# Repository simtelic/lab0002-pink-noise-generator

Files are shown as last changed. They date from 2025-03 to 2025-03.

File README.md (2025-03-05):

# Pink Noise Generator

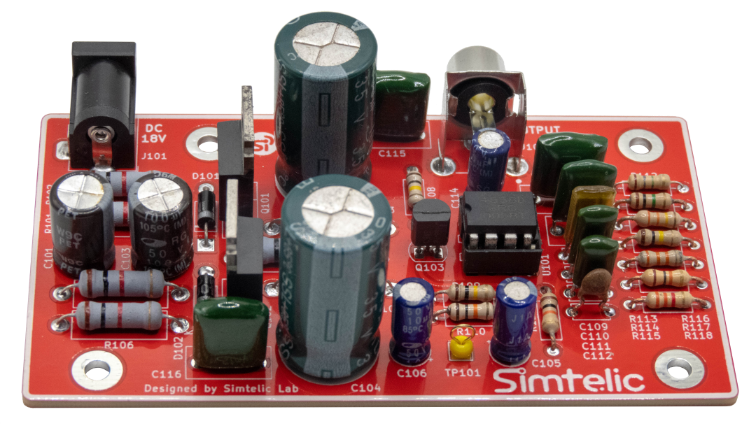
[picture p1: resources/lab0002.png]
LB0002 prototype build


This kit offers a simple yet effective DIY pink noise generator. It features a compact and user-friendly design that utilizes only three transistors and one operational amplifier, making it a cost-effective and educational option for exploring the unique characteristics of pink noise. All components are through-hole, ensuring that assembly is straightforward and suitable for hobbyists of varying skill levels.

The pink-noise generator operates with a DC power supply ranging from 12V to 18V and includes a single audio output that can be directly connected to a power amplifier or preamplifier for further amplification and playback.

This is an open hardware project, and all design files are available in this repository. You can also [order an unassembled DIY kit from Simtelic](https://simtelic.com/product/pink-noise-generator/), which includes the PCB and all the necessary components for assembly and testing.

[PCBWay](https://www.pcbway.com) sponsors this project, and you can [directly order the PCB](https://www.pcbway.com/project/shareproject/Analog_pink_noise_generator_595b019c.html) from them as well.

The [datasheet](https://simtelic.com/datasheet.php?id=lb0002) and [user manual](https://simtelic.com/datasheet.php?id=lb0002) for this project are available at [simtelic.com](https://simtelic.com).

## Bill of Materials

| Designator | Value | Quantity | Notes |
|---|---|---|---|
| C101,C103 | [100μF/25V](https://s.click.aliexpress.com/e/_omJ0Eoy) | 2 | |
| C102,C104 | [1000μF/25V](https://s.click.aliexpress.com/e/_olrI524) | 2 | |
| C105,C106,C114 | [10μF/25V](https://s.click.aliexpress.com/e/_ompkcr2) | 3 | |
| C107,C115,C116 | [0.1μF/50V](https://s.click.aliexpress.com/e/_okANxdw) | 3 | |
| C108 | [0.033μF/50V](https://s.click.aliexpress.com/e/_onlJl4o) | 1 | |
| C109 | [0.01μF/50V](https://s.click.aliexpress.com/e/_okQIYzA) | 1 | |
| C110 | [0.0033μF/50V](https://s.click.aliexpress.com/e/_oDFPQX2) | 1 | |
| C111 | [0.001μF/50V](https://s.click.aliexpress.com/e/_oDFPQX2) | 1 | |
| C112 | [330PF/50V](https://s.click.aliexpress.com/e/_oBugdCo) | 1 | |
| C113 | [100PF/50V](https://s.click.aliexpress.com/e/_oBugdCo) | 1 | |
| R101,R102,R104,R105,R106 | [1KΩ(5% 1W)](https://s.click.aliexpress.com/e/_oFf5dpE) | 5 | |
| R103,R107 | [2.2Ω(5% 1W)](https://s.click.aliexpress.com/e/_oFf5dpE) | 2 | |
| R108,R109,R115 | [100KΩ](https://s.click.aliexpress.com/e/_onyWV8u) | 3 | |
| R110,R111,R117 | [10KΩ](https://s.click.aliexpress.com/e/_onyWV8u) | 3 | |
| R112 | [1.8MΩ](https://s.click.aliexpress.com/e/_onyWV8u) | 1 | |
| R113 | [1MΩ](https://s.click.aliexpress.com/e/_onyWV8u) | 1 | |
| R114 | [330KΩ](https://s.click.aliexpress.com/e/_onyWV8u) | 1 | |
| R116 | [33KΩ](https://s.click.aliexpress.com/e/_onyWV8u) | 1 | |
| R118 | [3.3KΩ](https://s.click.aliexpress.com/e/_onyWV8u) | 1 | |
| D101,D102 | [1N4007](https://s.click.aliexpress.com/e/_oC87JiG) | 2 | https://www.vishay.com/docs/88503/1n4001.pdf |
| Q101 | [TIP31](https://s.click.aliexpress.com/e/_oDikbdi) | 1 | https://www.onsemi.com/download/data-sheet/pdf/tip31a-d.pdf |
| Q102 | [TIP32](https://s.click.aliexpress.com/e/_oDikbdi) | 1 | https://www.onsemi.com/download/data-sheet/pdf/tip32c-d.pdf |
| Q103 | [2SC945](https://s.click.aliexpress.com/e/_oCgKZjW) | 1 | https://datasheet.octopart.com/2SC945-Inchange-Semiconductor-datasheet-15979352.pdf |
| U101 | [NJM4558](https://s.click.aliexpress.com/e/_onCjzLQ) | 1 | https://www.nisshinbo-microdevices.co.jp/en/pdf/datasheet/NJM4558_E.pdf |
| J101 | [5.5mm DC Jack Socket](https://s.click.aliexpress.com/e/_o2awuTE) | 1 | |
| J102 | [RCA Jack Socket](https://s.click.aliexpress.com/e/_oEL5MTS) | 1 | |
| TP101 | [Test pin (optional)](https://s.click.aliexpress.com/e/_olBI9cC)  | 1 | |

*All resistors are 5% 1/4W unless otherwise noted*

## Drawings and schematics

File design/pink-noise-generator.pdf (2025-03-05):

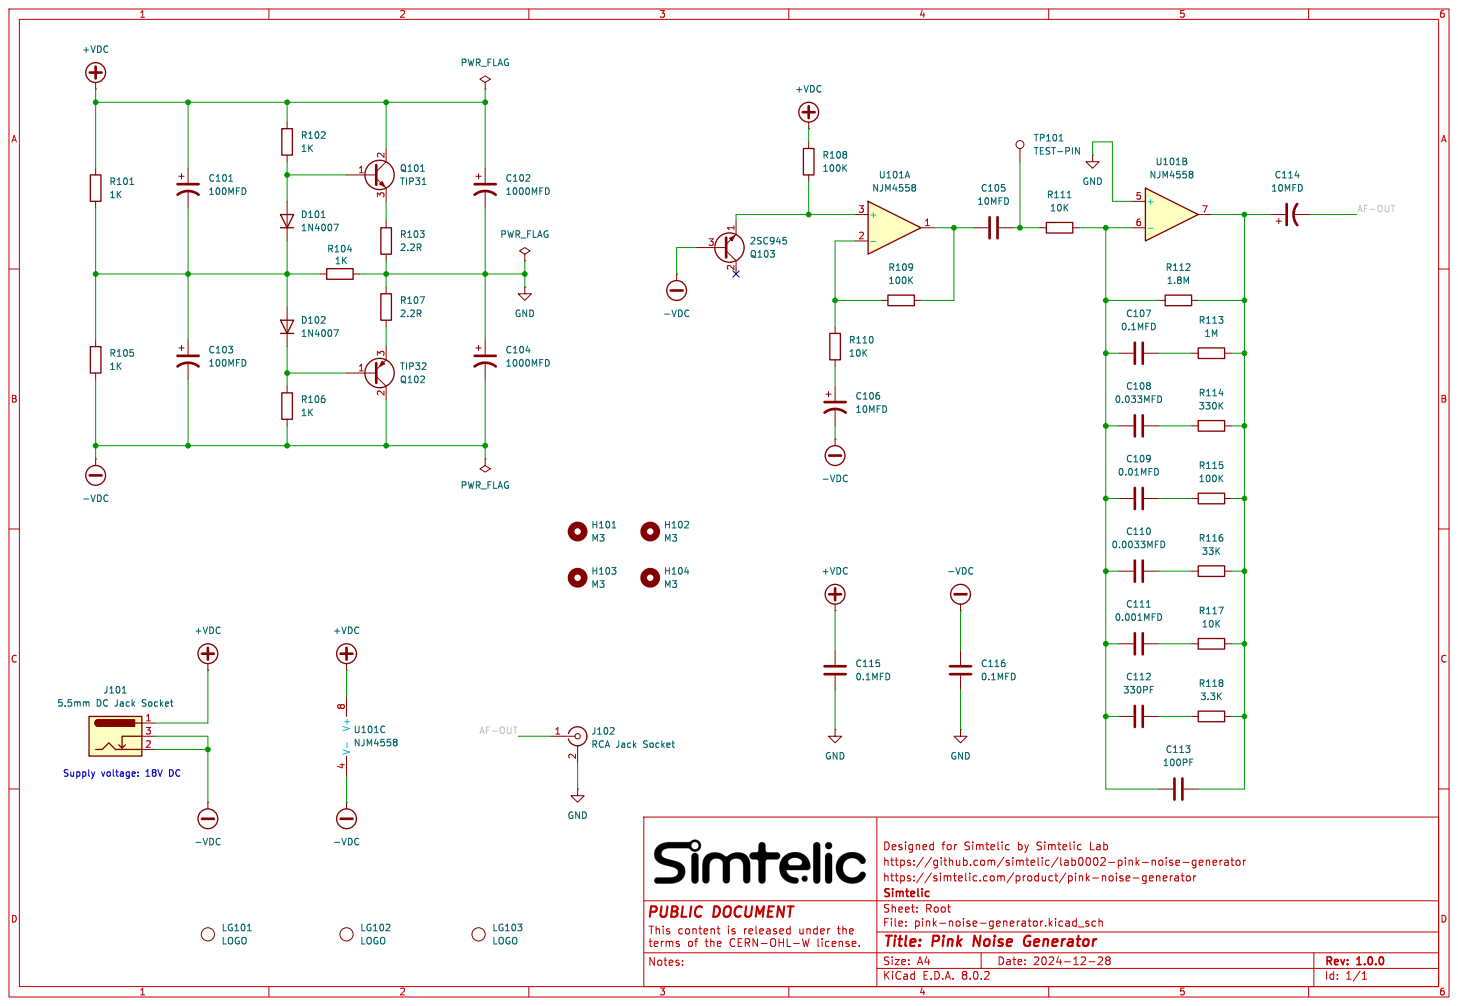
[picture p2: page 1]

J102 RCA Jack Socket GND

https://github.com/simtelic/lab0002-pink-noise-generator
https://simtelic.com/product/pink-noise-generator
Id: 1/1 Title: Pink Noise Generator File: pink-noise-generator.kicad_sch Sheet: Root Simtelic

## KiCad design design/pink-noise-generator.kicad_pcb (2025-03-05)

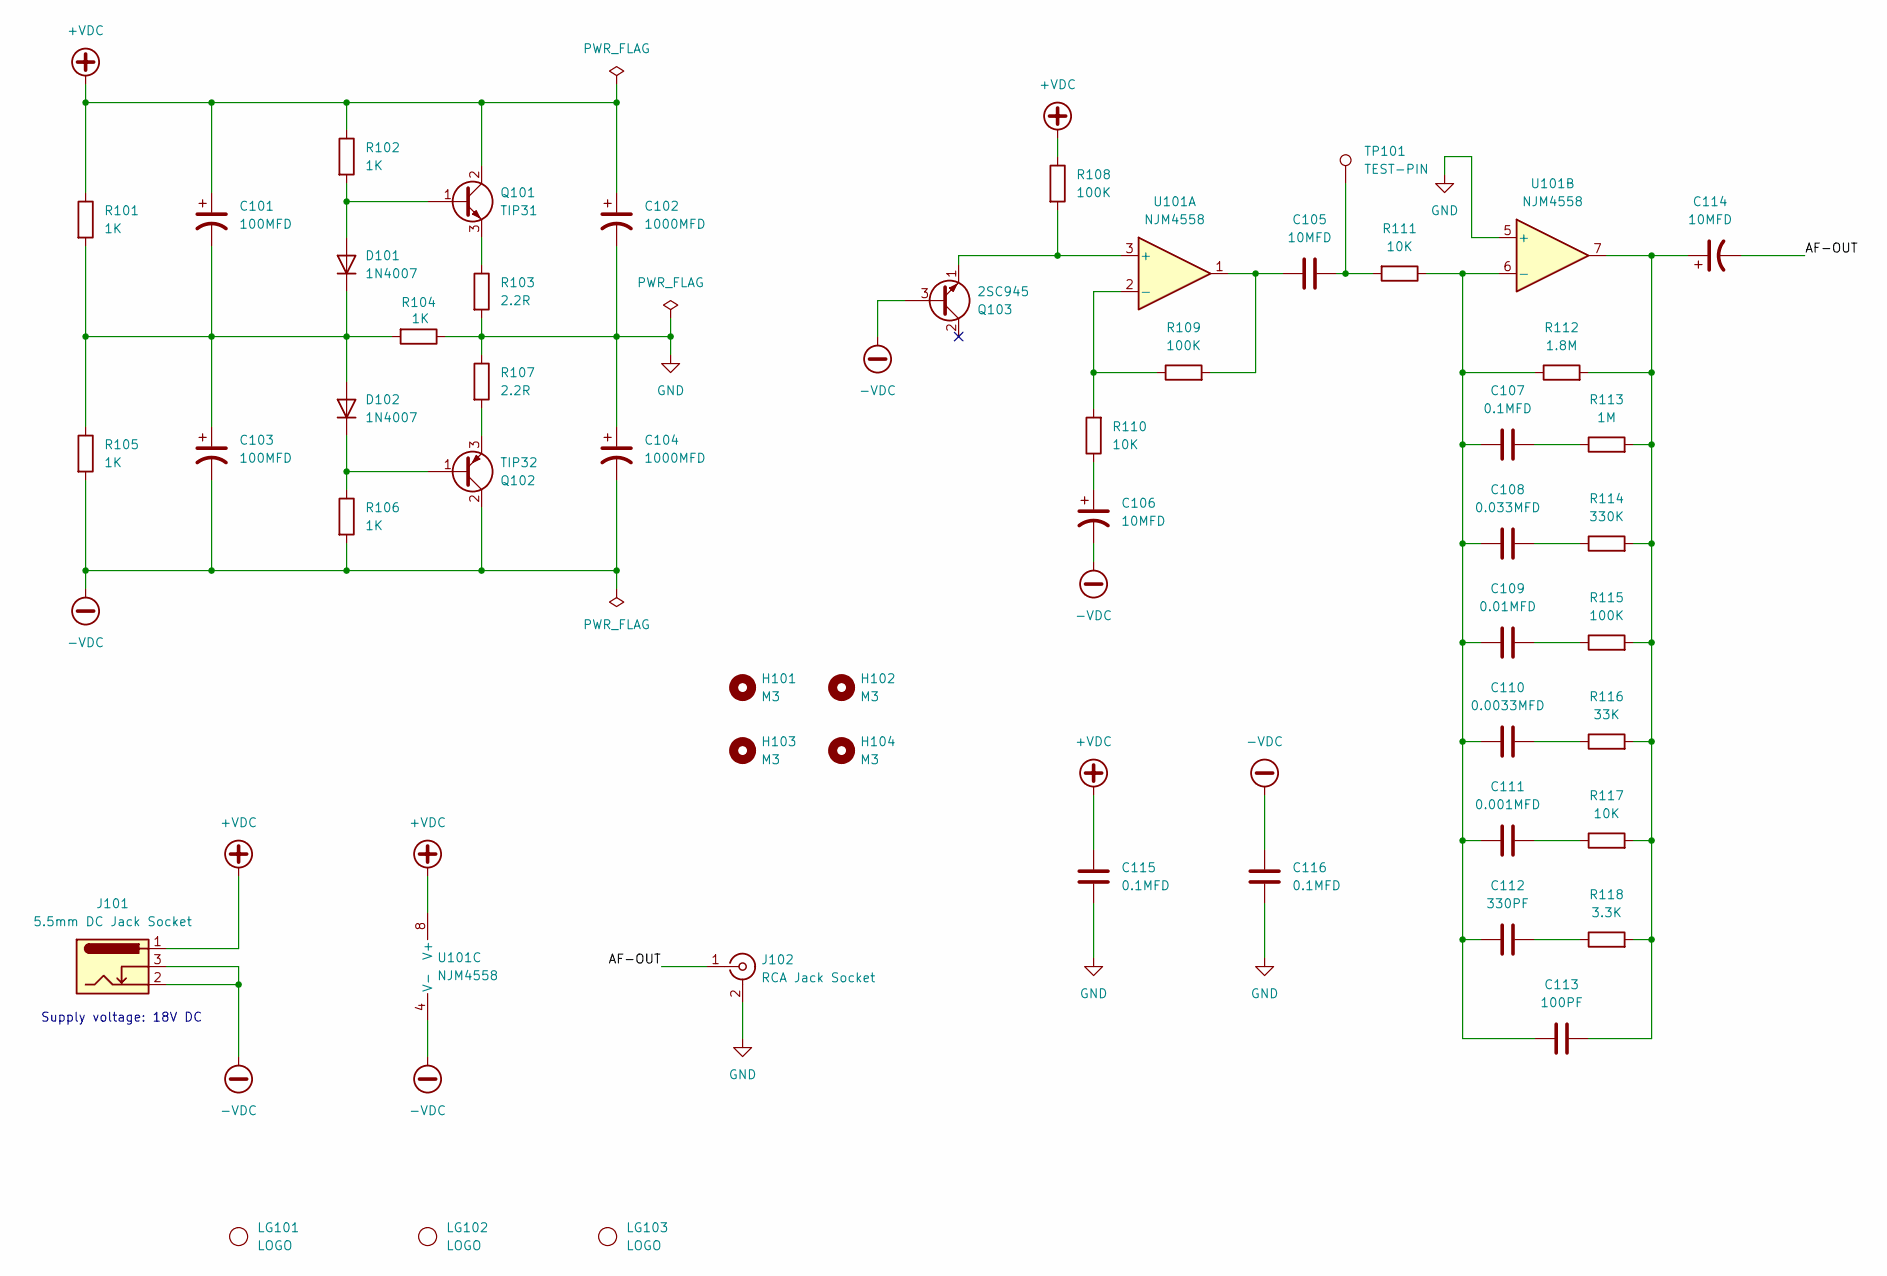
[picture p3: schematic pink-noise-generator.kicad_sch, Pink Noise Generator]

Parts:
C101, C103: 100MFD; CP_Radial_D6.3mm_P2.50mm
C102, C104: 1000MFD; CP_Radial_D12.5mm_P5.00mm
C105, C106, C114: 10MFD; CP_Radial_D5.0mm_P2.50mm
C107, C115, C116: 0.1MFD; C_Disc_D10.5mm_W5.0mm_P7.50mm
C108: 0.033MFD; C_Disc_D7.5mm_W5.0mm_P5.00mm
C109: 0.01MFD; C_Disc_D5.0mm_W2.5mm_P5.00mm
C110: 0.0033MFD; C_Disc_D5.0mm_W2.5mm_P5.00mm
C111: 0.001MFD; C_Disc_D5.0mm_W2.5mm_P5.00mm
C112: 330PF; C_Disc_D4.7mm_W2.5mm_P5.00mm
C113: 100PF; C_Disc_D4.7mm_W2.5mm_P5.00mm
D101, D102: 1N4007; D_DO-41_SOD81_P10.16mm_Horizontal
H101, H102, H103, H104: M3; MountingHole_3.2mm_M3_Pad
J101: 5.5mm DC Jack Socket; BarrelJack_Horizontal
J102: RCA Jack Socket; RCA Socket
LG101: LOGO; simtelic-5
LG102, LG103: LOGO; simtelic-name-5
Q101: TIP31; TO-220-3_Vertical
Q102: TIP32; TO-220-3_Vertical
Q103: 2SC945; TO-92L_HandSolder
R101, R102, R104, R105, R106: 1K; R_Axial_DIN0414_L11.9mm_D4.5mm_P15.24mm_Horizontal
R103, R107: 2.2R; R_Axial_DIN0414_L11.9mm_D4.5mm_P15.24mm_Horizontal
R108, R109, R115: 100K; R_Axial_DIN0207_L6.3mm_D2.5mm_P10.16mm_Horizontal
R110, R111, R117: 10K; R_Axial_DIN0207_L6.3mm_D2.5mm_P10.16mm_Horizontal
R112: 1.8M; R_Axial_DIN0207_L6.3mm_D2.5mm_P10.16mm_Horizontal
R113: 1M; R_Axial_DIN0207_L6.3mm_D2.5mm_P10.16mm_Horizontal
R114: 330K; R_Axial_DIN0207_L6.3mm_D2.5mm_P10.16mm_Horizontal
R116: 33K; R_Axial_DIN0207_L6.3mm_D2.5mm_P10.16mm_Horizontal
R118: 3.3K; R_Axial_DIN0207_L6.3mm_D2.5mm_P10.16mm_Horizontal
TP101: TEST-PIN; TestPoint_THTPad_2.5x2.5mm_Drill1.2mm
U101: NJM4558; DIP-8_W7.62mm_LongPads

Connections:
+VDC: C101.1, C102.1, C115.1, J101.1, Q101.2 (C), R101.1, R102.1, R108.1, U101.8 (V+)
-VDC: C103.2, C104.2, C106.2, C116.1, J101.2, J101.3, Q102.2 (C), Q103.3 (B), R105.2, R106.2, U101.4 (V-)
/AF-OUT: C114.2, J102.1 (In)
GND: C102.2, C104.1, C115.2, C116.2, J102.2 (Ext), R103.2, R104.1, R107.1, U101.5 (+)
unnamed: C105.1, R109.2, U101.1
unnamed: C105.2, R111.2, TP101.1
unnamed: C106.1, R110.1
unnamed: C107.2, R113.1
unnamed: C108.2, R114.1
unnamed: C109.2, R115.1
unnamed: C110.2, R116.1
unnamed: C111.2, R117.1
unnamed: C112.2, R118.1
unnamed: C113.2, C114.1, R112.2, R113.2, R114.2, R115.2, R116.2, R117.2, R118.2, U101.7
unnamed: D101.2 (A), Q101.1 (B), R102.2
unnamed: C101.2, C103.1, D101.1 (K), D102.2 (A), R101.2, R104.2, R105.1
unnamed: D102.1 (K), Q102.1 (B), R106.1
unnamed: Q101.3 (E), R103.1
unnamed: Q102.3 (E), R107.2
unnamed: Q103.1 (E), R108.2, U101.3 (+)
unnamed: R109.1, R110.2, U101.2 (-)
unnamed: C107.1, C108.1, C109.1, C110.1, C111.1, C112.1, C113.1, R111.1, R112.1, U101.6 (-)

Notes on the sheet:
Supply voltage: 18V DC

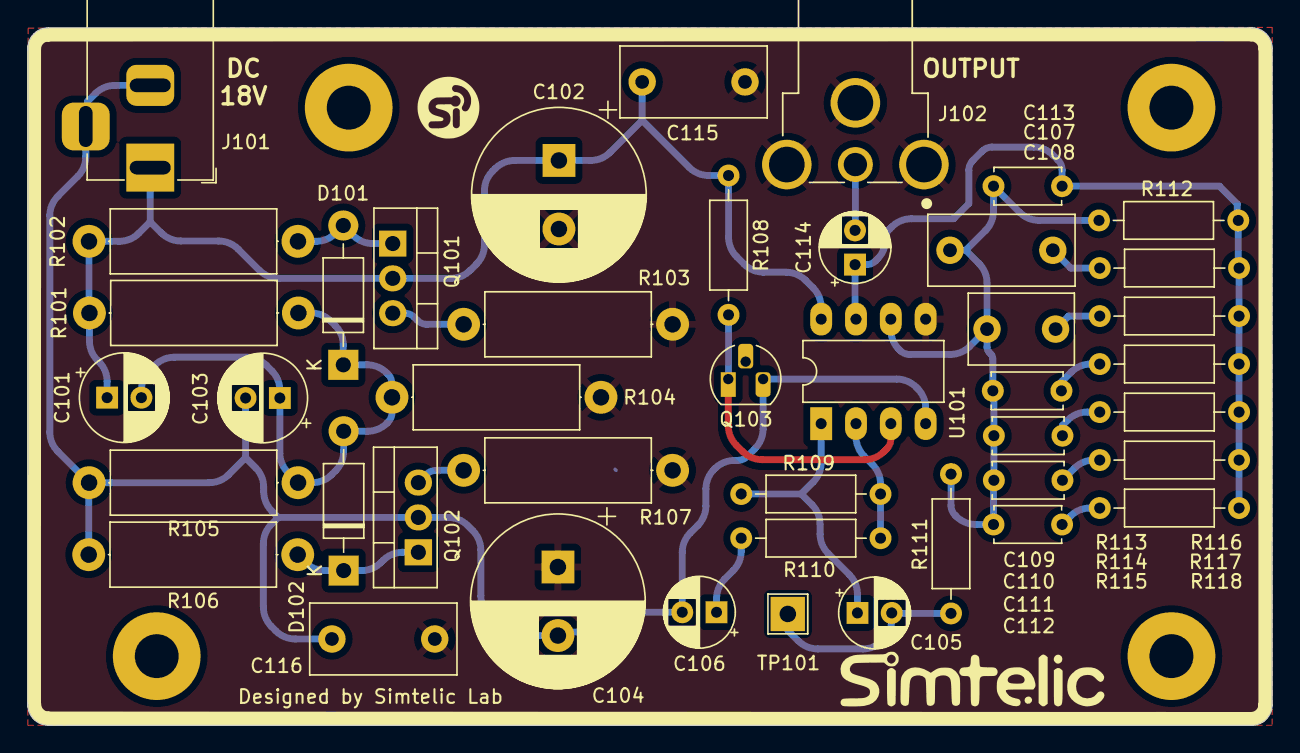
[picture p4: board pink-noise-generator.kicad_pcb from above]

Board: 2 copper layers, 90.8 x 50.9 mm, 50 parts (1 on the bottom side), 22 nets.

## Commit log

2025-03-05 Initial version of design files.
    [pink-noise-generator.kicad_pcb, pink-noise-generator.kicad_sch]
2025-03-05 Add image of the prototype build.
